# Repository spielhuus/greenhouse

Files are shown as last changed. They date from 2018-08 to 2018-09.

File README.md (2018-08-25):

# Greenhouse Sensors for Arduino

This is a hydrophonic greenhouse for the garden. The system is built with bato buckets....

## Electronic

* Air Temperature and Humidity

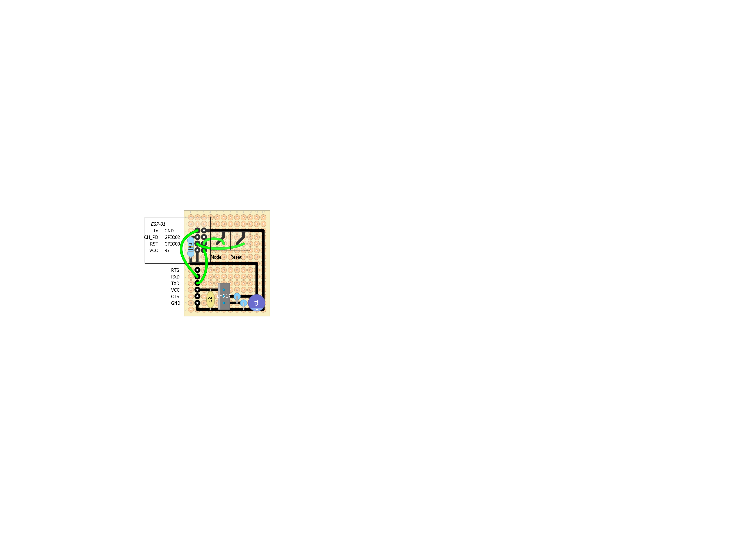
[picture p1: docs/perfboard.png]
perfboard
[](https://spielhuus.github.io/greenhouse/perfboard.png)

## Components 

|Amount | Type | Description  |
|:--- |:---|:-----|
| 1 | [DHT22](https://www.sparkfun.com/datasheets/Sensors/Temperature/DHT22.pdf)|Temperature/Humidity Sensor|
| 1 | [BMP180](https://ae-bst.resource.bosch.com/media/_tech/media/datasheets/BST-BMP180-DS000-12.pdf)|Digital Barometric Pressure Sensor Board Module compatible with with BMP085 For Arduino|
|1 | [DS1820](https://datasheets.maximintegrated.com/en/ds/DS18S20.pdf)|Stainless steel package Waterproof DS18b20 temperature probe temperature sensor 18B20 For Arduino|
|1 |[SR04T](https://www.jahankitshop.com/getattach.aspx?id=4635&Type=Product)|Waterproof Ultrasonic Range Distance Measurement Sensor| |
|1 |[ESP-01](http://www.microchip.ua/wireless/esp01.pdf)|Waterproof Ultrasonic Range Distance Measurement Sensor
|1 |[DS1307](https://www.sparkfun.com/datasheets/Components/DS1307.pdf)|RTC module|
|1 |[LM317](https://datasheet.octopart.com/LM317TG-ON-Semiconductor-datasheet-613672.pdf)|1.5 A Adjustable Output, Positive Voltage Regulator|
|1 | | Resistor 4.7 kΩ |

## Wiring

### DHT22

| Pin| 	Arduino Pin|
|----|---|
|VCC| 	5V|
|Data| 	D7|
|NC| 	NC|
|GND| 	GND|

[Temperature Monitoring With DHT22 & Arduino](https://create.arduino.cc/projecthub/attari/temperature-monitoring-with-dht22-arduino-15b013)

### BMP180

| Pin| 	Arduino Pin|
|----|---|
|VCC| 	3.3V|
|GND| 	GND|
|SCL| 	A5|
|SDA| 	A4|

[BMP085 Barometric Pressure Sensor Quickstart](https://www.sparkfun.com/tutorials/253)

### DS1820

| Pin| 	Arduino Pin|
|----|---|
|VCC| 	3.3V|
|GND| 	GND|
|DATA| 	A2|

There needs to be a 4.7 kΩ pull-up resistor between Data and VCC.

[DS18B20 (digital temperature sensor) and Arduino](https://create.arduino.cc/projecthub/TheGadgetBoy/ds18b20-digital-temperature-sensor-and-arduino-9cc806)

### TODO SR04T

| Pin| 	Arduino Pin|
|----|---|
|VCC| 	3.3V|
|GND| 	GND|
|DATA| 	A2|

[Waterproof Ultrasonic Range Distance Measurement Sensor](http://qqtrading.com.my/waterproof-ultrasonic-range-distance-measurement-sensor-sr04t)

### ESP-01

| Pin| 	Arduino Pin|
|----|---|
|Rx| 	Pin1/Rx|
|Tx| 	Pin2/Tx|
|CH-PD| 	3.3V|
|RST| NC |
|VCC| 3.3V |
|GND|GND|
|GPIOx|NC|

[Getting Started With the ESP8266 ESP-01](https://www.instructables.com/id/Getting-Started-With-the-ESP8266-ESP-01/)

https://www.deviceplus.com/how-tos/arduino-guide/esp8266-setup-tutorial-using-arduino/

### DS-1307

| Pin| 	Arduino Pin|
|----|---|
|VCC| 	5V|
|GND| 	GND|
|SDL| 	Analog Pin 5|
|SDA| Analog PIN 4 |

[DS1307 Real-Time Clock Modul mit einem Arduino ansteuern](https://www.frag-duino.de/index.php/maker-faq/26-ds1307-real-time-clock-modul-mit-arduino-ansteuern)

## Links

* [How many Devices can you Connect to the I2C Bus?](https://www.bluedot.space/tutorials/how-many-devices-can-you-connect-on-i2c-bus/)

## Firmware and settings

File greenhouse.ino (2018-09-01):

// Boost Software License - Version 1.0 - August 17th, 2003
//
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
// The copyright notices in the Software and this entire statement, including
// the above license grant, this restriction and the following disclaimer,
// must be included in all copies of the Software, in whole or in part, and
// all derivative works of the Software, unless such copies or derivative
// works are solely in the form of machine-executable object code generated by
// a source language processor.
//
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
//IMPORTANT: change packet size in PubSub.h to 200

#include <Wire.h>
#include <Adafruit_BMP085.h>
#include <OneWire.h>
#include <DallasTemperature.h>
#include <DHT.h>;
#include <WiFiEspClient.h>
#include <WiFiEsp.h>
#include <WiFiEspUdp.h>
#include <PubSubClient.h>
#include "SoftwareSerial.h"

#define NETWORK //compile without network for testing

// Configuration
#define THINGS_TITLE "Greenhouse Sensors"
#define WIFI_AP "<SSID>"
#define WIFI_PASSWORD "<KEY>"
#define TOKEN "<API KEY>"
char thingsboardServer[] = "<SERVER IP>";

#define INTERVAL 300000
#define ONE_WIRE_BUS 6
#define DHTPIN 7
#define DHTTYPE DHT22   // DHT 22  (AM2302)
#define echoPin 2 // SR04 Echo Pin
#define trigPin 4 // SR04 Trigger Pin
#define LEDPin 13 // SR04 Onboard LED
#define RX 3 //ESP RX
#define TX 5 //ESP TX
#define BUFFER_SIZE 100

// Setup a oneWire instance to communicate with any OneWire devices
// (not just Maxim/Dallas temperature ICs)
OneWire oneWire(ONE_WIRE_BUS);
// Pass our oneWire reference to Dallas Temperature.
DallasTemperature sensors(&oneWire);

Adafruit_BMP085 bmp;
DHT dht(DHTPIN, DHTTYPE);

// Initialize the Ethernet client object
WiFiEspClient espClient;
PubSubClient client(espClient);
SoftwareSerial soft(RX, TX);

int status = WL_IDLE_STATUS;
unsigned long lastSend;

void setup() {
#ifndef NETWORK
  Serial.begin(9600);
#endif

  //start BMP180
  if (!bmp.begin()) {
    while (1) {}
  }

  // Start DS
  sensors.begin();
  dht.begin();

  //HC-SR04 Ping distance sensor
  pinMode(trigPin, OUTPUT);
  pinMode(echoPin, INPUT);

  //setup wifi
#ifdef NETWORK
  InitWiFi();
  client.setServer( thingsboardServer, 1883 );
  lastSend = 0;
#endif
}

unsigned long time_  = 0;

void loop() {

  if ( time_ > 0 && millis() < time_ )
  {return;}

  time_ = millis() + ( INTERVAL );

  sensors.requestTemperatures(); // Send the command to get temperatures

  char attributes[BUFFER_SIZE];
  int position = 0;

  float _bmp_temp = bmp.readTemperature();
  float _dht_temp = dht.readTemperature();
  float _dht_humidity = dht.readHumidity();
  int32_t _bmp_pressure = bmp.readPressure();
  //  float _bmp_altitude = bmp.readAltitude();
  //  int32_t  _bmp_sealevel_pressure = bmp.readSealevelPressure();
  //  float _bmp_real_altitude = bmp.readAltitude(101500);
  float _ds_temperature = sensors.getTempCByIndex(0);

  //    const char* _template = "{\"T2\":%d.%02d, \"T1\":%d.%02d, \"f\":%d.%02d, \"atm\":%lu, \"atma\":%d.%02d, \"atmps\":%lu, \"atmsr\":%d.%02d, \"Tw\":%d.%02d, \"h\":%d}";
  const char* _template = "{\"T2\":%d.%02d, \"T1\":%d.%02d, \"f\":%d.%02d, \"atm\":%lu, \"Tw\":%d.%02d, \"h\":%d}";
  int _length = snprintf ( attributes, BUFFER_SIZE, _template,
                           (int)_bmp_temp, (int)(_bmp_temp * 100.0) % 100,
                           (int)_dht_temp, (int)(_dht_temp * 100.0) % 100,
                           (int)_dht_humidity, (int)(_dht_humidity * 100.0) % 100,
                           (unsigned long)_bmp_pressure,
                           //                            (int)_bmp_altitude, (int)(_bmp_altitude * 100.0) % 100,
                           //                            _bmp_sealevel_pressure,
                           //                            (int)_bmp_real_altitude, (int)(_bmp_real_altitude * 100.0) % 100,
                           (int)_ds_temperature, (int)(_ds_temperature * 100.0) % 100,
                           get_distance() );

  if ( _length > BUFFER_SIZE ) {
    sprintf( attributes, "{\"error\":\"message to long\"}" );
  }

  //  payload.toCharArray( attributes, BUFFER_SIZE );

#ifndef NETWORK
  Serial.print("(");
  Serial.print(strlen(attributes));
  Serial.print(")");
  Serial.print(attributes);
  Serial.println();
  Serial.println("---");
#endif

#ifdef NETWORK
  status = WiFi.status();
  if ( status != WL_CONNECTED) {
    while ( status != WL_CONNECTED) {
      // Connect to WPA/WPA2 network
      status = WiFi.begin(WIFI_AP, WIFI_PASSWORD);
      delay(500);
    }
  }

  if ( !client.connected() ) {
    reconnect();
  }

  client.publish( "v1/devices/me/telemetry", attributes );
#endif
}

long get_distance() {

  //Variables for SR04T
  int maximumRange = 200; // Maximum range needed
  int minimumRange = 0; // Minimum range needed
  long duration, distance = 0; // Duration used to calculate distance
  int count = 0;

  while ( distance == 0 && count < 10 ) {
    /* The following trigPin/echoPin cycle is used to determine the
      distance of the nearest object by bouncing soundwaves off of it. */
    digitalWrite(trigPin, LOW);
    delayMicroseconds(2);

    digitalWrite(trigPin, HIGH);
    delayMicroseconds(10);

    digitalWrite(trigPin, LOW);
    duration = pulseIn(echoPin, HIGH);

    //Calculate the distance (in cm) based on the speed of sound.
    distance = duration / 58.2;

    if (distance >= maximumRange || distance <= minimumRange) {

#ifndef NETWORK
      Serial.print("wrong distance:"); Serial.println(distance);
#endif

      distance = 0;
      /* Send a negative number to computer and Turn LED ON
        to indicate "out of range" */
      digitalWrite(LEDPin, HIGH);
      count++;
      delay(200);

    } else {
      /* Send the distance to the computer using Serial protocol, and
        turn LED OFF to indicate successful reading. */
      digitalWrite(LEDPin, LOW);
    }
  }
  return distance;
}

void InitWiFi() {
  // initialize serial for ESP module
  soft.begin(9600);
  // initialize ESP module
  WiFi.init(&soft);
  // check for the presence of the shield
  if (WiFi.status() == WL_NO_SHIELD) {
    // don't continue
    while (true);
  }

  // attempt to connect to WiFi network
  while ( status != WL_CONNECTED) {
    // Connect to WPA/WPA2 network
    status = WiFi.begin(WIFI_AP, WIFI_PASSWORD);
    delay(500);
  }
}

void reconnect() {
  // Loop until we're reconnected
  while (!client.connected()) {
    // Attempt to connect (clientId, username, password)
    if ( !client.connect(THINGS_TITLE, TOKEN, NULL) ) {
      // Wait 5 seconds before retrying
      delay( 1 );
    }
  }
}

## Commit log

2018-08-19 add frizin sketch
    [treenhouse sketch.fzz]
2018-08-25 add perfboard image
    [treenhouse sketch.fzz]
